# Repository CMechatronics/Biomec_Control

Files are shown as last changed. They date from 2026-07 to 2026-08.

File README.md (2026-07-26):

# Control. Biomec UMA

Biomec es una iniciativa de la Universidad de Málaga orientada al desarrollo de soluciones de ingeniería aplicadas a prótesis de mano electrónicas. El proyecto parte del estudio de señales electromiográficas (EMG), obtenidas a partir de la actividad muscular, para convertirlas en información útil de control.

La señal biológica se adquiere mediante un sistema de medida basado en el ADS1198 y se comunica con un microcontrolador encargado de procesarla. A partir de ese tratamiento es posible definir umbrales de activación y generar órdenes de control que permitan accionar los motores de la prótesis de forma coordinada.

El trabajo integra varias disciplinas técnicas, entre ellas mecánica, control, electrónica y diseño de sistemas embebidos.

## Objetivo del repositorio

Este repositorio reúne el trabajo del departamento de control y sirve como base para organizar el avance del proyecto, documentar decisiones técnicas y centralizar tareas, diseños y pruebas de desarrollo.

## Contexto técnico

El planteamiento del sistema se apoya en la adquisición diferencial de bioseñales, el acondicionamiento de la señal y su posterior interpretación para control. En la práctica, esto exige una interfaz fiable entre el cuerpo y la electrónica, así como un tratamiento adecuado del ruido, la amplitud de la señal y la sincronización con el sistema de actuación.

## Alcance

- Estudio y adquisición de señales EMG.
- Interfaz entre el sensor biológico y la electrónica de control.
- Procesamiento de señal para detección de umbrales y eventos.
- Integración con actuadores para el control de la mano protésica.

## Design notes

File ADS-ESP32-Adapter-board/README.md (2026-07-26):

# Placa adaptadora intermedia entre la PCB del ADS1198 y un ESP32 compatible.

## Resumen

Este proyecto busca mejorar la compatibilidad entre distintas placas ESP32 que se comunican con el ADS1198. La idea es disponer de una interfaz intermedia que permita cambiar de microcontrolador sin rediseñar todo el sistema cada vez que un modelo deje de estar disponible o presente problemas de suministro.

## Objetivo

Aumentar la flexibilidad y la mantenibilidad del sistema, reduciendo la dependencia de una sola placa ESP32. Esto facilita la sustitución de hardware en caso de avería y mejora la disponibilidad de recambios en el taller.

## Contexto técnico

El ADS1198 es un front-end analógico de bajo ruido, con 8 canales y 16 bits, orientado a mediciones ECG/EEG. Su control se realiza desde el ESP32 mediante SPI y algunas líneas GPIO. Además, el sistema contempla una separación entre la zona no aislada y la zona aislada de la placa.

## Base de partida

La primera rama del proyecto parte de un ESP32-C3 DevKitC-02 como referencia de hardware. A partir de ese punto se toma como base la siguiente configuración:

- Microcontrolador ESP32-C3 de arquitectura RISC-V de un solo núcleo.
- Conectividad Wi-Fi 2.4 GHz y Bluetooth LE 5.
- Alimentación por 3.3 V y 5 V en la placa de desarrollo.
- Puerto USB para programación y depuración.
- Pines GPIO expuestos para SPI, control y señales auxiliares.

### Mapa de señales usado en el proyecto

| Señal del proyecto | GPIO | Función |
| --- | --- | --- |
| FE_RESET | GPIO0 | Reinicio / control del ADS |
| FE_DRDY | GPIO1 | Señal de datos listos |
| SPI1_MISO | GPIO2 | Entrada de datos SPI |
| FE_START | GPIO3 | Inicio de conversión |
| SPI1_SCLK | GPIO6 | Reloj SPI |
| SPI1_MOSI | GPIO7 | Salida de datos SPI |
| FE_CS | GPIO10 | Chip select del ADS |

### Pines de soporte de la placa

- 3V3 para alimentación lógica.
- 5V para entrada de alimentación de la placa de desarrollo.
- GND como referencia común.
- USB D+ y USB D- para comunicación serie / JTAG según la configuración.
- EN / RST y BOOT para arranque y programación.

## Motivación

El uso de una placa adaptadora permite trabajar con diferentes modelos de ESP32 sin modificar la base del sistema. Esto reduce la fragilidad ante discontinuidades de fabricación o cambios de disponibilidad, como puede ocurrir con determinadas versiones del ESP32, por ejemplo la DevKit-02 o variantes concretas del C3.

## Líneas de trabajo previstas

- Validar el funcionamiento con distintos modelos de ESP32.
- Probar el rendimiento del ESP32 C3 SuperMini sobre la placa actual.
- Preparar el diseño en KiCad para futuras revisiones y prototipos.

## Herramientas

- KiCad para el diseño electrónico.
- Prototipado previo antes de fabricar la versión final.

## Estado del proyecto

El proyecto se encuentra en fase de definición y validación. El siguiente paso es comprobar la compatibilidad real con distintos ESP32 antes de cerrar una versión definitiva de la PCB.

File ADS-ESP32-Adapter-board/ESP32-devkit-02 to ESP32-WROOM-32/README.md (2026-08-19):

# Placa adaptadora: ESP32-DevKit-C3-02 → ESP32-WROOM-32

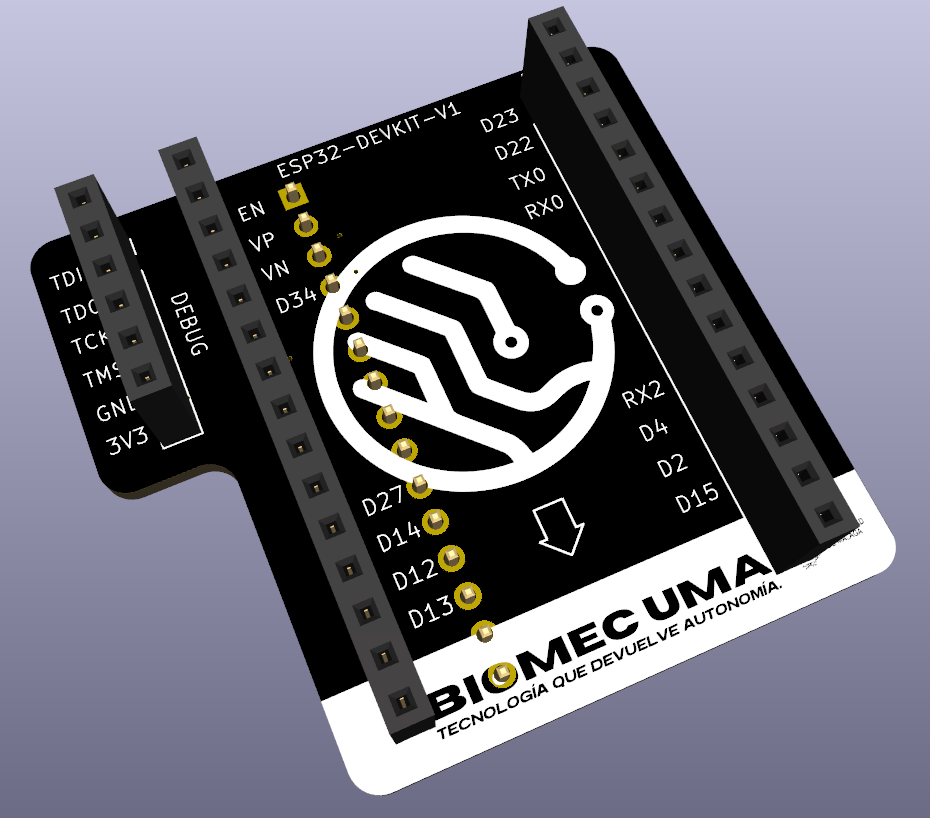
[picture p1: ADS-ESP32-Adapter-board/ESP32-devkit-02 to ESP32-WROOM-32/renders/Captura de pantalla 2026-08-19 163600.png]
Render de la PCB


## Resumen ejecutivo

Este directorio contiene el diseño y documentación de la placa adaptadora que permite migrar del ESP32-C3 DevKitC-02 al ESP32-WROOM-32, manteniendo compatibilidad total con la interfaz del ADS1198 y reduciendo la dependencia de hardware específico.

## Motivación técnica

El ESP32-C3 DevKitC-02 presenta limitaciones de disponibilidad en el mercado y restricciones en número de pines GPIO. El ESP32-WROOM-32 ofrece:
- Mayor capacidad de procesamiento (2 núcleos vs 1)
- Más pines GPIO disponibles (34 vs 13)
- Mayor memoria RAM y flash
- Mejor disponibilidad en el mercado
- Mejor rendimiento energético en aplicaciones con WiFi/Bluetooth

La placa adaptadora permite cambiar de microcontrolador sin modificar la base del sistema ni el firmware de procesamiento de señal.

---

## Especificaciones técnicas comparativas

### Arquitectura y procesamiento

| Aspecto | ESP32-C3 DevKit-02 | ESP32-WROOM-32 |
|---|---|---|
| **Arquitectura** | RISC-V 32-bit | Xtensa 32-bit dual-core |
| **Núcleos** | 1 @ 160 MHz | 2 @ 80/160 MHz (configurable) |
| **Caché** | 16 KB I + 8 KB D | 32 KB I + 32 KB D (per core) |
| **Memoria RAM** | 400 KB | 520 KB |
| **Flash externo** | 4 MB | 4/8/16 MB (configurable) |
| **Voltaje** | 3.3 V | 3.3 V |
| **Consumo activo** | ~40-60 mA | ~80-100 mA (dual-core) |

### Conectividad

| Característica | ESP32-C3 | ESP32-WROOM-32 |
|---|---|---|
| **WiFi** | 802.11 b/g/n (2.4 GHz) | 802.11 b/g/n (2.4 GHz) |
| **Bluetooth** | LE 5.0 only | Classic 5.0 + LE 4.2 |
| **Antena** | Integrada PCB | Integrada PCB |
| **TX Power** | +15 dBm (WiFi), +4 dBm (BLE) | +20 dBm (WiFi), +4 dBm (BLE) |

### Periféricos disponibles

| Periférico | ESP32-C3 | ESP32-WROOM-32 |
|---|---|---|
| **UART** | 2 (GPIO20/21, GPIO5/6 alt) | 3 (GPIO1/3, GPIO9/10, GPIO17/16 alt) |
| **SPI** | 1 maestro (GPIO6/7/2/10) | 3 (SPI2 en GPIO12-15, SPI3 en GPIO17-22) |
| **I²C** | 2 | 2 (GPIO21/22) |
| **GPIO analógicos** | 11 canales ADC | 12 canales ADC (algunos compartidos con SPI) |
| **PWM** | 6 canales | 16 canales |
| **Timer** | 2 | 4 |
| **RTC** | Sí | Sí |

---

## Mapa de equivalencias GPIO

### Interfaz del ADS1198 (SPI principal)

| Función | ESP32-C3 DevKit-02 | ESP32-WROOM-32 | Notas |
|---|---|---|---|
| **FE_RESET** | GPIO0 | GPIO32 | Reinicio del front-end ADS1198 |
| **FE_DRDY** | GPIO1 | GPIO35 | Data Ready del ADS1198 |
| **SPI_MISO** | GPIO2 | GPIO12 | ESP32 ← ADS1198 (datos) |
| **FE_START** | GPIO3 | GPIO33 | Inicio de conversión del ADS |
| **SPI_CLK** | GPIO6 | GPIO14 | Reloj SPI |
| **SPI_MOSI** | GPIO7 | GPIO13 | ESP32 → ADS1198 (datos) |
| **FE_CS** | GPIO10 | GPIO15 | Chip Select del ADS1198 |

### Pines de soporte general

| Función | ESP32-C3 | ESP32-WROOM-32 | Observaciones |
|---|---|---|---|
| **3V3** | Pin 2 | Pin 2 | Alimentación lógica |
| **5V** | Pin 1 | Pin 1 | Entrada de alimentación externa |
| **GND** | Pins 3, 4, 5 | Pins 3, 4, 5 | Referencia común (múltiples puntos) |
| **USB D+** | GPIO19 | GPIO25 | No usado en este diseño |
| **USB D-** | GPIO18 | GPIO26 | No usado en este diseño |
| **EN/RST** | GPIO9 | GPIO EN | Reinicio del microcontrolador |
| **BOOT** | GPIO8 | GPIO0 alt | Modo de arranque |

### GPIO disponibles adicionales

Pines libres para futuras expansiones o depuración:

**ESP32-WROOM-32:**
- GPIO4, GPIO5, GPIO23, GPIO27, GPIO34, GPIO36, GPIO37, GPIO38, GPIO39
- GPIO25, GPIO26 (para USB si se requiere, no usado actualmente)

---

## Consideraciones de diseño

### Alimentación

- **Voltaje de entrada recomendado:** 5V ± 0.5V
- **Regulador:** LDO de bajo ruido para generar 3.3V
- **Capacitores:** 
  - Entrada: 10 µF (para estabilidad de línea de 5V)
  - Salida: 10 µF + 100 nF (cerca del ESP32-WROOM-32)
- **Consumo pico esperado:** ~150 mA (con WiFi activo)

### Aislamiento de ruido

El ADS1198 es un front-end de bajo ruido sensible a perturbaciones electromagnéticas:

- Separación física entre zona de alimentación del ADS1198 y ESP32-WROOM-32
- Plano de GND continuo bajo el ADS1198
- Vías de paso (via stitching) alrededor del área de señal analógica
- Capacitores de desacoplamiento locales (100 nF) para cada pin de alimentación del ADS

### Interfaces SPI

**ESP32-WROOM-32 SPI2 (usado):**
- Frecuencia configurada: 2 MHz (conservadora para estabilidad)
- Bus compartido con la interfaz SD (cuidado si se agrega soporte SD)
- Modo: SPI Master, CPOL=0, CPHA=0

**Líneas de control especiales:**
- **DRDY** es una línea de interrupción activa baja
- **CS** debe mantenerse baja durante toda la transacción SPI
- **RESET** debe pulsarse al menos 2 µs

### Protección ESD

- Protección ESD serie en líneas de señal analógica (optional, depende de ambiente)
- Protección TVS en líneas de GPIO si están expuestas

---

## Estructura del proyecto

```
ESP32-devkit-02 to ESP32-WROOM-32/
├── docs/
│   ├── planteamiento.pdf          # Análisis y justificación técnica
│   └── README.md                  # Este archivo
├── hardware/
│   └── kicad/
│       ├── esp32c3-esp32Wroom/   # Diseño principal de la placa
│       │   ├── esp32c3-esp32Wroom.kicad_sch
│       │   ├── esp32c3-esp32Wroom.kicad_pcb
│       │   ├── esp32c3-esp32Wroom.kicad_pro
│       │   └── .history/          # Historial de cambios
│       └── MiESP32Lib/            # Librería de símbolos personalizados
│           └── MiESP32Lib.kicad_sym
├── src/                           # Firmware en desarrollo
├── lib/                           # Librerías reutilizables
├── signal_processing/             # Módulos de procesamiento de señal
└── tools/                         # Scripts y utilidades
```

---

## Cambios de firmware necesarios

### Configuración de pines en PlatformIO/Arduino

```cpp
// Configuración SPI
#define SPI_MISO  12
#define SPI_MOSI  13
#define SPI_CLK   14
#define SPI_CS    15

// Señales de control del ADS1198
#define ADS_RESET 32
#define ADS_DRDY  35
#define ADS_START 33

// Verificar que el SPI esté configurado para SPI2:
// hspi_host en lugar de vspi_host
```

### Inicialización del SPI

```cpp
spi_bus_config_t buscfg = {
    .mosi_io_num = SPI_MOSI,
    .miso_io_num = SPI_MISO,
    .sclk_io_num = SPI_CLK,
    .quadwp_io_num = -1,
    .quadhd_io_num = -1,
    .max_transfer_sz = 4094,
};

esp_err_t ret = spi_bus_initialize(HSPI_HOST, &buscfg, DMA_CHAN_AUTO);
```

---

## Validación y pruebas

### Checklist de verificación hardware

- [ ] Continuidad en pistas de alimentación (5V, 3.3V, GND)
- [ ] Ausencia de cortocircuitos entre pistas de señal
- [ ] Voltaje de salida del regulador: 3.3V ± 0.1V
- [ ] Continuidad en líneas SPI (CLK, MOSI, MISO, CS)
- [ ] Continuidad en líneas de control (RESET, DRDY, START)
- [ ] Resistencia de Pull-up en DRDY (si está configurado)

### Pruebas funcionales

1. **Lectura de registro de identity del ADS1198**
   - Leer registro 0x00 (debe retornar ID del chip)
   - Repetir 10 veces para validar comunicación estable

2. **Adquisición de datos**
   - Configurar ADS1198 en modo continuo
   - Leer datos continuamente
   - Verificar rango esperado (±12V entrada → ±32768 digital)

3. **Rendimiento**
   - Medir frecuencia de muestreo efectiva (debe ser ≥ 1000 Hz)
   - Medir latencia de DRDY a lectura completa

4. **WiFi/Bluetooth** (si se requiere)
   - Verificar conectividad WiFi
   - Verificar rango de señal
   - Evaluar impacto en ruido de ADC

---

## Diferencias operacionales clave

### Ventajas del ESP32-WROOM-32

✅ **Dual-core:** Posibilidad de ejecutar procesamiento pesado en core 1 mientras core 0 gestiona SPI  
✅ **Más memoria:** Espacio para algoritmos de filtrado más complejos  
✅ **Mejor rendimiento WiFi:** Core dedicado disponible  
✅ **Mayor disponibilidad:** Componente más común en el mercado  
✅ **Menores costos:** Precio más estable y comprobado  

### Limitaciones a considerar

⚠️ **Consumo superior:** ~50 mA adicionales con dual-core activo  
⚠️ **Mayor tamaño:** PCB del módulo es más grande  
⚠️ **Configuración SPI:** Usa SPI2 en lugar de SPI1  
⚠️ **Pin layout diferente:** Requiere rediseño de placa adaptadora  
⚠️ **ADC compartido:** Algunos pines ADC comparten funciones con SPI (GPIO12, GPIO13, GPIO14, GPIO15)

---

## Hoja de ruta

| Fase | Tarea | Estado | Target |
|---|---|---|---|
| 1 | Diseño esquemático y layout PCB | ✅ Completado | - |
| 2 | Fabricación de prototipo | ⏳ En progreso | 2-3 semanas |
| 3 | Validación eléctrica del prototipo | ⏳ En progreso | - |
| 4 | Adaptación de firmware a pines nuevos | ⏳ En progreso | - |
| 5 | Pruebas funcionales del sistema completo | ⏹️ Pendiente | - |
| 6 | Generación de PCB final | ⏹️ Pendiente | - |
| 7 | Documentación de fabricación | ⏹️ Pendiente | - |

---

## Referencias y recursos

### Datasheets
- [ESP32-C3 Datasheet](https://www.espressif.com/sites/default/files/documentation/esp32-c3_datasheet_en.pdf)
- [ESP32 (WROOM-32) Datasheet](https://www.espressif.com/sites/default/files/documentation/esp32_datasheet_en.pdf)
- [ADS1198 Datasheet](https://www.ti.com/lit/ds/symlink/ads1198.pdf)

### Librerías y soporte
- [ESP-IDF (Espressif IoT Development Framework)](https://github.com/espressif/esp-idf)
- [Arduino-ESP32](https://github.com/espressif/arduino-esp32)
- [KiCad Documentation](https://docs.kicad.org/)

### Herramientas recomendadas
- KiCad 6.0+ para editar esquemáticos y PCB
- PlatformIO o Arduino IDE para programación
- Logic Analyzer de bajo coste para debug SPI

---

## Contacto y soporte

Para consultas técnicas sobre este diseño, consultar la documentación de Biomec UMA o la rama `develop` del repositorio.

**Última actualización:** Agosto 2026  
**Autor:** Departamento de Control, Biomec UMA  
**Licencia:** Ver archivo LICENSE en la raíz del repositorio

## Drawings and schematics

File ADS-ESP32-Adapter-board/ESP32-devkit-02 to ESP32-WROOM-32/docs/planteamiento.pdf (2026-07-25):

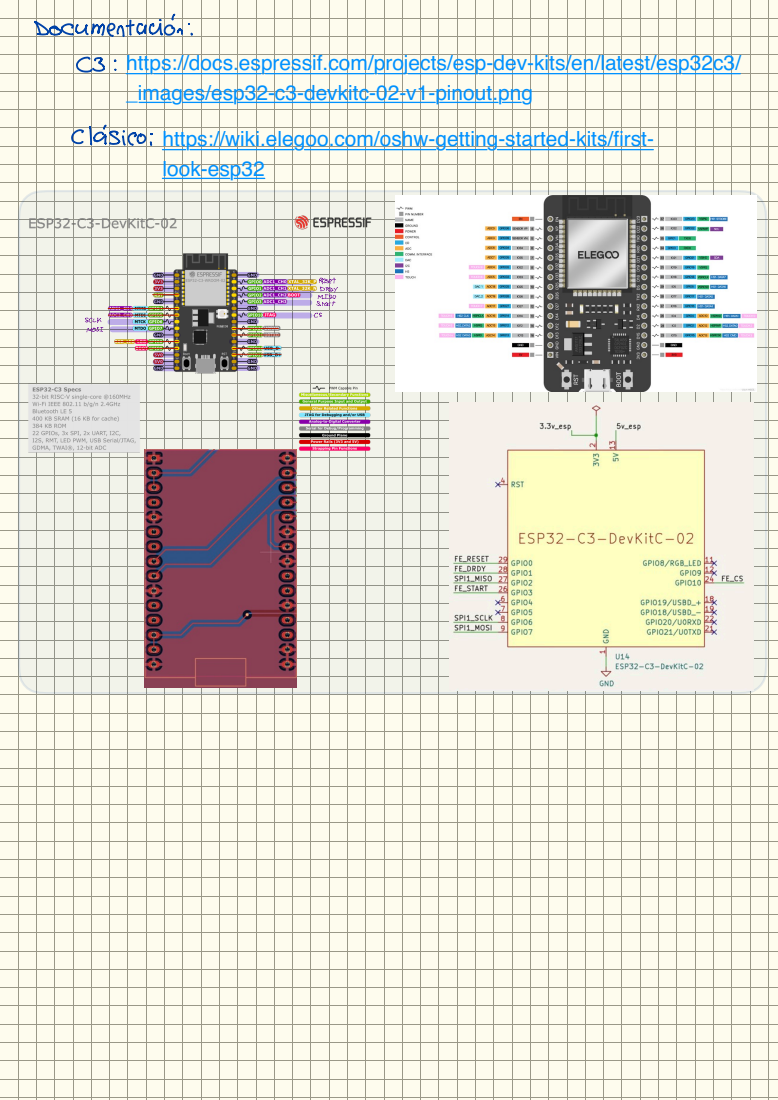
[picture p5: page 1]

https://docs.espressif.com/projects/esp-dev-kits/en/latest/esp32c3/
_images/esp32-c3-devkitc-02-v1-pinout.png

https://wiki.elegoo.com/oshw-getting-started-kits/first-
look-esp32

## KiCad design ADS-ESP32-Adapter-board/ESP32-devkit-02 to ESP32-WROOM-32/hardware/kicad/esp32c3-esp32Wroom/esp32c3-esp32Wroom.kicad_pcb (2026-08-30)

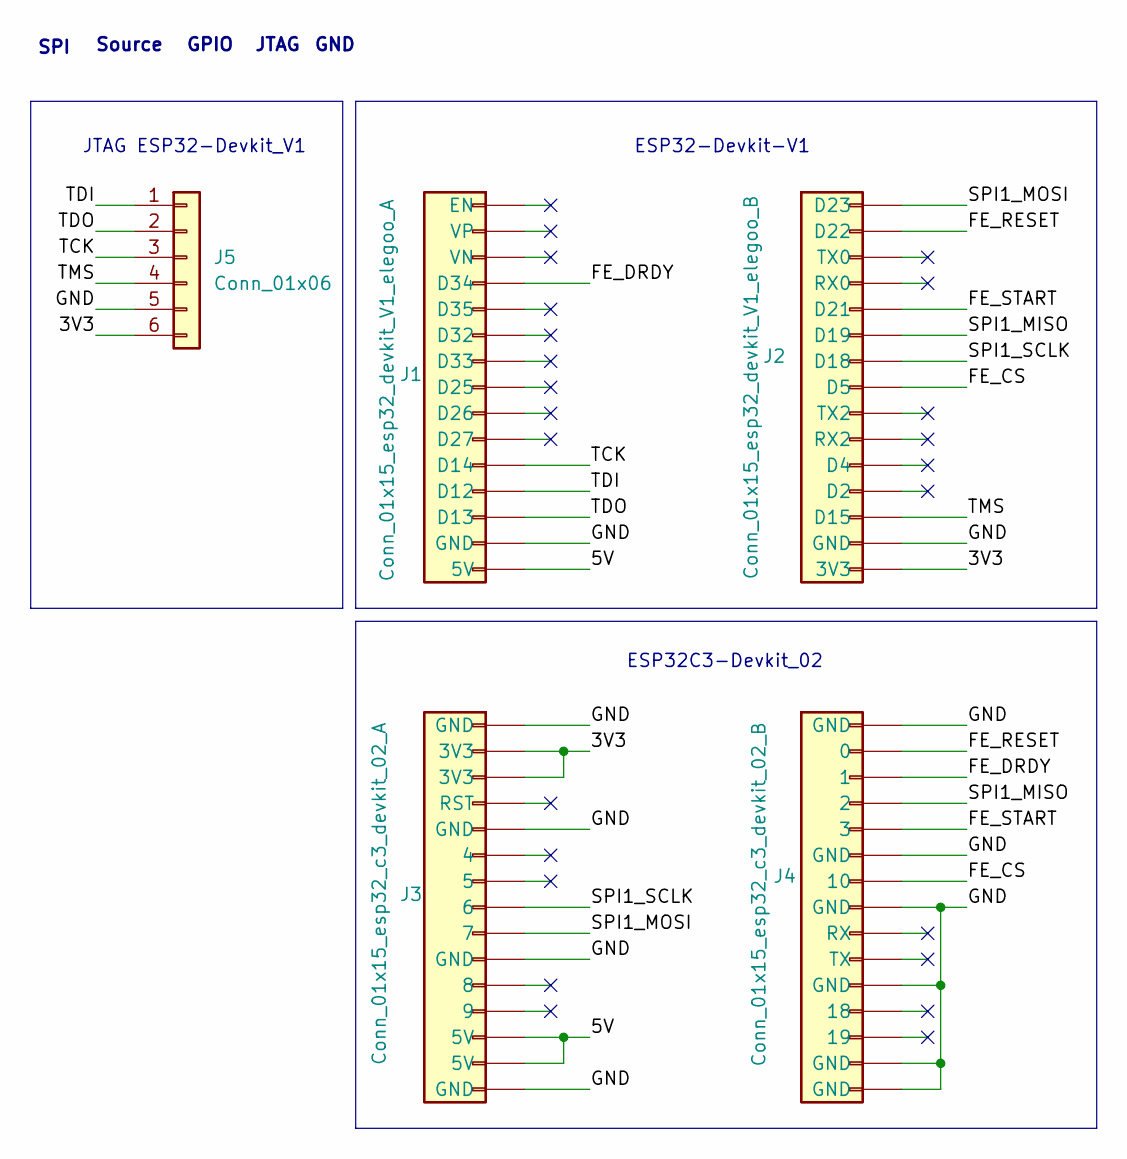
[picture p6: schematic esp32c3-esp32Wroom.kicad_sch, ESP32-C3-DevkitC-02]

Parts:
J1: Conn_01x15_esp32_devkit_V1_elegoo_A; PinSocket_1x15_P2.54mm_Vertical
J2: Conn_01x15_esp32_devkit_V1_elegoo_B; PinSocket_1x15_P2.54mm_Vertical
J3: Conn_01x15_esp32_c3_devkit_02_A; PinHeader_1x15_P2.54mm_Vertical
J4: Conn_01x15_esp32_c3_devkit_02_B; PinHeader_1x15_P2.54mm_Vertical
J5: Conn_01x06; PinSocket_1x06_P2.54mm_Vertical

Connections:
/3V3: J2.15 (3V3), J3.2 (3V3), J3.3 (3V3), J5.6
/5V: J1.15 (5V), J3.13 (5V), J3.14 (5V)
/FE_CS: J2.8 (D5), J4.7 (10)
/FE_DRDY: J1.4 (D34), J4.3 (1)
/FE_RESET: J2.2 (D22), J4.2 (0)
/FE_START: J2.5 (D21), J4.5 (3)
/GND: J1.14 (GND), J2.14 (GND), J3.1 (GND), J3.5 (GND), J3.10 (GND), J3.15 (GND), J4.1 (GND), J4.6 (GND), J4.8 (GND), J4.11 (GND), J4.14 (GND), J4.15 (GND), J5.5
/SPI1_MISO: J2.6 (D19), J4.4 (2)
/SPI1_MOSI: J2.1 (D23), J3.9 (7)
/SPI1_SCLK: J2.7 (D18), J3.8 (6)
/TCK: J1.11 (D14), J5.3
/TDI: J1.12 (D12), J5.1
/TDO: J1.13 (D13), J5.2
/TMS: J2.13 (D15), J5.4

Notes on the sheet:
ESP32C3-Devkit_02
JTAG
GND
GPIO
Source
ESP32-Devkit-V1
JTAG ESP32-Devkit_V1
SPI

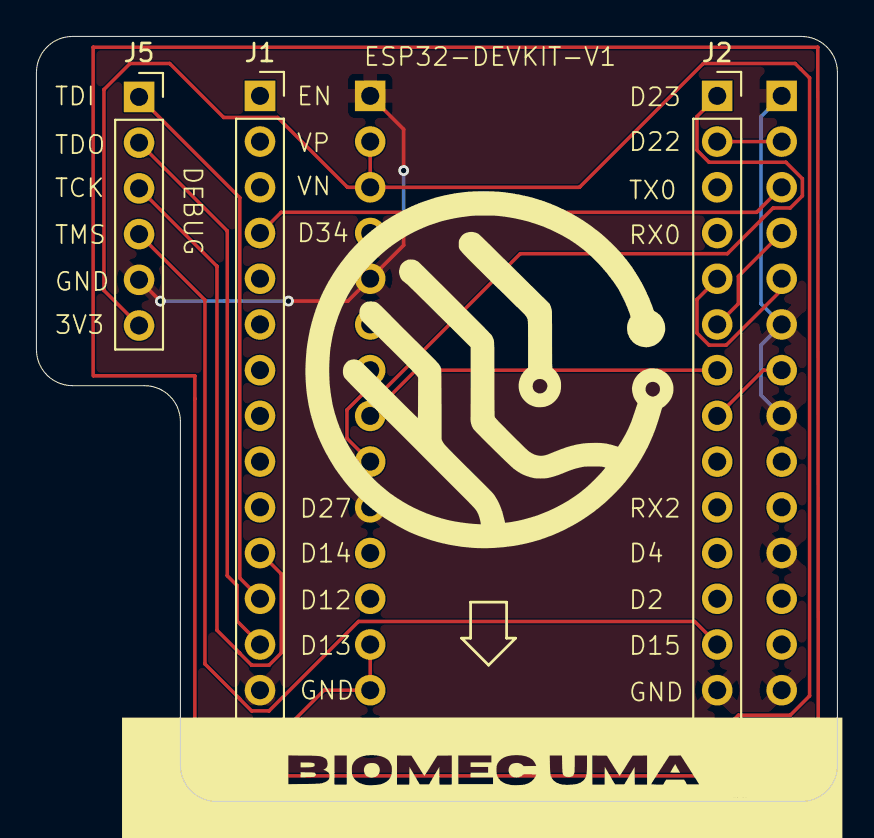
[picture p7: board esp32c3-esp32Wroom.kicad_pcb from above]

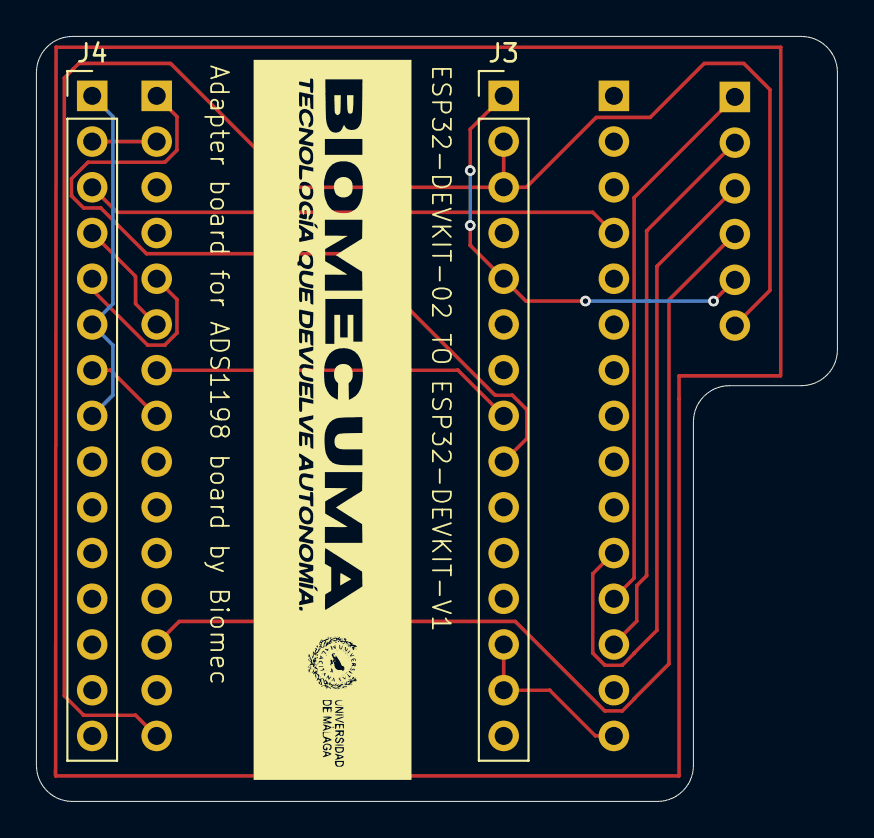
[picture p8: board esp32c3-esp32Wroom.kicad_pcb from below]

Board: 2 copper layers, 44.5 x 42.5 mm, 5 parts (2 on the bottom side), 14 nets.

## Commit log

2026-07-25 Add .history and KiCad temp files to .gitignore
2026-07-25 Add KiCad hardware designs: ESP32-C3 to ESP32 adapter and MiESP32Lib symbol library
    [esp32c3-esp32Wroom.kicad_pcb, esp32c3-esp32Wroom.kicad_sch]
2026-07-26 Add .gitkeep files to maintain directory structure for lib, signal_processing, src, and tools
    [esp32c3-esp32Wroom.kicad_pcb, esp32c3-esp32Wroom.kicad_sch]
2026-07-26 Refactor code structure for improved readability and maintainability
    [esp32c3-esp32Wroom.kicad_pcb, esp32c3-esp32Wroom.kicad_sch]
2026-07-26 Add initial project structure and README for Biomec Control adapter board
    - Created directories for lib, signal_processing, src, and tools with .gitkeep files to maintain structure.
    - Added README.md detailing project overview, objectives, technical context, signal mapping, and future work.
    [esp32c3-esp32Wroom.kicad_pcb, esp32c3-esp32Wroom.kicad_sch]
2026-07-26 Add documentation PDF for ESP32 development kit resources
2026-07-26 Add initial README for ADS-ESP32 adapter board project
2026-08-17 Add lock files for ESP32-WROOM-32 hardware configuration
    - Created new lock files: ~esp32c3-esp32Wroom.kicad_pcb.lck and ~esp32c3-esp32Wroom.kicad_pro.lck
    - Both files contain hostname and username information for the development environment.
    [esp32c3-esp32Wroom.kicad_sch]
2026-08-17 Remove lock file for ESP32-WROOM-32 hardware configuration
2026-08-19 Esquema terminado, PCB terminada pero falta agregar algún símbolo que indique la posición, asegurar que las ancho pistas es adecuado y que no haya acoplamiento entre pistas.
    [esp32c3-esp32Wroom.kicad_pcb, esp32c3-esp32Wroom.kicad_sch]
2026-08-19 Remove lock files for ESP32-WROOM-32 hardware configuration
2026-08-19 Update README.md to use HTML img tag for PCB front image
2026-08-30 Add additional text annotations to schematic and update visible layers in PCB layout
    - Added JTAG, GND, GPIO, Source, and SPI text annotations to the schematic for better clarity and reference.
    - Updated the visible layers in the PCB layout file to include grid visibility.
    [esp32c3-esp32Wroom.kicad_pcb, esp32c3-esp32Wroom.kicad_sch]
